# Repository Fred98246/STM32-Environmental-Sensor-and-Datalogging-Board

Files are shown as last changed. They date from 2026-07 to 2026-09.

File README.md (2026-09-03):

# Custom STM32 Environmental Sensor & Datalogging Board

## Project Overview
This repository contains the complete design files and source code for a custom, battery-powered STM32 microcontroller board designed for environmental monitoring and data logging. Measuring at a compact 40 x 58 mm, the board features integrated temperature, humidity, and ambient light sensors, alongside an SD card slot for local data storage. It includes a complete Li-Ion power management system with USB-C charging, load sharing, and battery protection. 

The user interface is driven by a rotary encoder and an external SPI display, making it suitable for standalone automated environments like humidity control or ambient monitoring.

## Repository Structure
*   **Hardware:** Contains the complete KiCad E.D.A. project files, including the schematic and the 4-layer PCB layout.
*   **Manufacturing:** Includes the generated Gerber files, Drill files, and sheets with the Bill of Materials (BOM) required for PCB fabrication and assembly.
*   **Firmware:** Contains the `STM32CubeMX` (`.ioc`) configuration file for peripheral initialization and the C/C++ code with the needed drivers.
*   **docs**: Contains component datasheets and a detailed Bill of Materials (BOM) spreadsheet

## Hardware Implementation Details

### Core Processing
*   **Microcontroller:** The board is powered by the STM32F103C8T6 ARM Cortex-M3 MCU.
*   **Clocking:** A 16MHz crystal oscillator (LFXTAL085871) is implemented to provide the precise clocking required for stable USB communication. 
*   **Debugging/Programming:** Connector for SWD programming, via ST-Link V2.

### Power Management
The power architecture is designed for safe, continuous operation whether plugged in or running on battery:
*   **Battery Charging:** Handled by the MCP73831/2 IC, drawing 5V from the USB-C port to charge a connected Li-Ion cell.
*   **Battery Protection:** An AP9101C IC, paired with dual ZXMN3B14F N-Channel MOSFETs, protects the battery from overcharge, overdischarge, and overcurrent scenarios.
*   **Load Sharing:** An AO3401A P-Channel MOSFET and an SS14 Schottky diode create a seamless load-sharing circuit. This ensures the system runs directly off USB power when plugged in, allowing the battery to charge optimally without system load interference.
*   **Regulation:** An AP2112K-3.3TRG1 LDO provides a stable 3.3V supply for the MCU and logic.

### Sensors & Interfaces
*   **Environmental Sensing:** Utilizes the SHT3x-DIS for high-precision temperature and humidity tracking via I2C.
*   **Light Sensing:** Incorporates the OPT3001DNPRQ1 ambient light sensor, also operating on the I2C bus.
*   **Storage:** A Molex 47219-2001 MicroSD card receptacle is routed via high-speed SPI for data logging in txt file.
*   **Connectivity:** USB-C port configured for USB 2.0 data and power. D3V3XA4B10LP TVS diode arrays are placed on both the USB data lines and the SD card lines to protect against electrostatic discharge (ESD).
*   USB-CDC Virtual COM Port Interface: Integrated full-speed USB communication between the STM32 and host PC, enabling real-time serial telemetry and diagnostic logging for hardware bring-up and physical fault isolation.
*   **User Input:** Hardware debounced rotary encoder footprint with integrated push-button functionality.

## Design Challenges & Signal Integrity
Designing this board within a 40x58mm footprint required careful attention to PCB stackup and signal routing:

*   **Component Footprints & Tolerances:** Extensive review of manufacturer datasheets was required to ensure precise footprint creation and component placement within the restricted 40x58mm board area.
*   **4-Layer Stackup:** To accommodate the component density and maintain strict signal integrity, a 4-layer PCB was utilized (Top Signal, Ground Plane, Power Plane, Bottom Signal). This continuous internal ground plane is critical for providing short return paths for high-frequency signals and minimizing electromagnetic interference (EMI). 
*   **USB Differential Routing:** The USB D+ and D- lines require 90-ohm differential impedance matching. The 4-layer stackup allowed for calculating precise trace widths and spacing over the internal ground plane to hit this impedance target, ensuring reliable USB enumeration and data transfer.
*   **MicroSD SPI Speeds:** Because SD card SPI operates at moderate speeds, it does not require strict impedance matching or length tuning. The 4-layer stackup provided the flexibility to route these signals easily through vias while maintaining a solid ground reference to minimize general EMI.
*   **Mixed-Signal Placement:** Analog sensor lines (I2C for SHT3x and OPT3001) are physically separated from high-speed digital traces (USB, SPI, and the 16MHz crystal) to prevent digital switching noise from coupling into the sensitive environmental readings.
*   **Firmware Architecture:** The C/C++ codebase leverages STM32 HAL libraries, structured with modular driver functions and a streamlined main loop to ensure non-blocking sensor reads and efficient peripheral management.

## Operational Flow & User Interface: 
The firmware is structured around an event-driven state machine that handles user interaction, data logging, and strict power efficiency:

*   **Startup & Menu Navigation:** The system is awakened by a physical press of the rotary encoder. The TFT display initializes and presents an interactive menu where the user can select to view Temperature, Humidity, or Ambient Light.
*   **Active Monitoring:** Upon selection, the screen continuously updates with real-time readings from the designated I2C sensor.
*   **Concurrent Datalogging & Telemetry:** While the system is awake, it automatically mounts the FATFS file system and appends the sensor readings to a `.txt` file on the MicroSD card at strict 10-second intervals. Simultaneously, this data is continuously broadcast over the USB-CDC COM port to a connected PC for live monitoring.
*   **Low-Power Sleep Mode:** To conserve battery, if the system detects no rotary encoder rotation or button clicks for 2 minutes, it automatically gracefully closes the SD card file, powers down the display, and puts the STM32 into a low-power `STOP` state. A subsequent button press triggers an EXTI hardware interrupt, waking the system back to full operation instantly.

## 🚀 Future Scope: Closed-Loop Automation
While currently operating as a standalone datalogger, this board was engineered to serve as the precision sensor node for future automated control systems. By linking the onboard environmental telemetry to external physical actuators (such as fans, humidifiers, or motorized blinds), the hardware will transition into a dynamic closed-loop control environment. 

The high-resolution empirical data currently gathered via the SD card and USB interface provides the foundation for mathematical system identification. This allows the physical environment's behavior to be accurately modeled in software like MATLAB, enabling the future calculation of transfer functions and the implementation of tuned PID or automated sequential control logic directly onto the STM32.

*   **Schematic**:




* **PCB**:



* **3D View**:



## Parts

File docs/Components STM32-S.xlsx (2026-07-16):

Component name | Part number | Data sheet | Price (Mouser) | Quantity
STM 32 Microconroler | STM32F103C8T6 | https://www.st.com/resource/en/datasheet/stm32f103c8.pdf | 6.05 € | 1
LDO Power 3.3V | AP2112K-3.3TRG1 | https://www.diodes.com//assets/Datasheets/AP2112.pdf | 0.22 € | 1
Li-Ion Battery Charger | MCP73831/2 | https://www.mouser.es/datasheet/3/282/1/MCP73831_Family_Data_Sheet_DS20001984H.pdf | 0.68 € | 1
Battery Protection | AP9101C | https://4donline.ihs.com/images/VipMasterIC/IC/DIOD/DIOD-S-A0007229744/DIOD-S-A0007229744-1.pdf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 | 0.25 € | 1
N-Channel Mosfets | ZXMN3B14F | https://www.mouser.es/datasheet/3/175/1/ZXMN3B14F.pdf | 1.11 € | 2
Temp/Humidity Sensor | SHT3x-DIS | https://www.mouser.es/datasheet/3/1278/1/080A7561932A882253F24EE2F1BFBB37F2FE6DCAD49B4883533175650C45BFA9.pdf | 2.13 € | 1
Light sensor | OPT3001DNPRQ1 | https://www.ti.com/lit/ds/symlink/opt3001-q1.pdf?ts=1783836413148 | 1.38 € | 1
P-Channel MOSFET | AO3401A | https://www.aosmd.com/sites/default/files/res/datasheets/AO3401A.pdf | 0.72 € | 1
Schottky diode | SS14 | https://www.vishay.com/docs/88746/ss12.pdf | 0.31 € | 1
TVS DIODE ARRAY for USB | D3V3XA4B10LP | https://www.diodes.com/assets/Datasheets/D3V3XA4B10LP.pdf | 0.36 € | 2
MicroSD Card | 47219-2001 | https://www.molex.com/en-us/products/part-detail-pdf/472192001?display=pdf | 1.41 € | 1
Cristal 16MHz | LFXTAL085871 | https://www.mouser.es/datasheet/3/1460/1/LFXTAL085871.pdf | 0.50 € | 1
Rotary Encoder | EC12 | https://es.aliexpress.com/item/1005005196870256.html?scm_id=1007.40050.354490.0&scm-url=1007.40050.354490.0 | €1.41 | 1
Manufacturing JLCPCB |  | https://cart.jlcpcb.com/quote?spm=jlcpcb.Public.2006 | €6.09 | 1
 |  | Total | 24.09

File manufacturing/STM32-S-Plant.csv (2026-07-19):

Reference | Qty | Value | DNP | Exclude from BOM | Exclude from Board | Footprint | Datasheet
C1,C2 | 2 | 1u |  |  |  | Capacitor_SMD:C_0402_1005Metric | ~
C3,C4 | 2 | 4.7u |  |  |  | Capacitor_SMD:C_0805_2012Metric | ~
C5,C7,C8,C9,C11,C12,C16,C17,C18,C24 | 10 | 100n |  |  |  | Capacitor_SMD:C_0402_1005Metric | ~
C6,C10,C15 | 3 | 10u |  |  |  | Capacitor_SMD:C_0805_2012Metric | ~
C19,C20,C21 | 3 | 10n |  |  |  | Capacitor_SMD:C_0402_1005Metric | ~
C22,C23 | 2 | 10p |  |  |  | Capacitor_SMD:C_0402_1005Metric | ~
D1,D6 | 2 | D3V3XA4B10LP-7 |  |  |  | SamacSys_Parts:D3V3XA4B10LP7 | https://www.diodes.com/assets/Datasheets/D3V3XA4B10LP.pdf
D4 | 1 | Charging LED |  |  |  | Capacitor_SMD:C_0603_1608Metric | ~
D5 | 1 | SS14 |  |  |  | SamacSys_Parts:DIOM5026X230N | https://datasheet.lcsc.com/szlcsc/1911061831_SLKORMICRO-Elec-SS14_C444721.pdf
IC1 | 1 | AP2112K-3.3TRG1 |  |  |  | SamacSys_Parts:SOT95P270X145-5N | https://www.diodes.com//assets/Datasheets/AP2112.pdf
IC2 | 1 | AP9101CAK-AKTRG1 |  |  |  | SamacSys_Parts:SOT95P270X145-5N | https://www.diodes.com/assets/Datasheets/AP9101C.pdf
IC4 | 1 | MCP73831-2ATI_OT |  |  |  | SamacSys_Parts:SOT95P270X145-5N | http://ww1.microchip.com/downloads/en/DeviceDoc/20001984g.pdf
IC6 | 1 | OPT3001DNPRQ1 |  |  |  | SamacSys_Parts:SON65P200X200X65-7N-D | http://www.ti.com/lit/gpn/OPT3001-Q1
IC7 | 1 | SHT3X-DIS |  |  |  | SamacSys_Parts:SON50P250X250X100-9N-D
IC8 | 1 | STM32F103C8T6 |  |  |  | SamacSys_Parts:QFP50P900X900X160-48N | https://www.st.com/resource/en/datasheet/stm32f103c8.pdf
J1 | 1 | Battery Connector |  |  |  | Connector_PinHeader_2.54mm:PinHeader_1x02_P2.54mm_Vertical | ~
J2 | 1 | USB_C_Receptacle_USB2.0_16P |  |  |  | Connector_USB:USB_C_Receptacle_GCT_USB4105-xx-A_16P_TopMnt_Horizontal | https://www.usb.org/sites/default/files/documents/usb_type-c.zip
J3 | 1 | DISPLAY |  |  |  | Connector_PinHeader_2.54mm:PinHeader_1x08_P2.54mm_Vertical | ~
J4 | 1 | 47219-2001 |  |  |  | SamacSys_Parts:472192001 | http://www.molex.com/molex/products/datasheet.jsp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
J5 | 1 | DEBUG CONNECTOR ST-LINK |  |  |  | Connector_PinHeader_2.54mm:PinHeader_1x07_P2.54mm_Vertical | ~
Q1 | 1 | AO3401A |  |  |  | SamacSys_Parts:SOT95P280X125-3N | http://www.aosmd.com/pdfs/datasheet/AO3401A.pdf
Q2,Q3 | 2 | ZXMN3B14FTA |  |  |  | SamacSys_Parts:ZXMN3B14FTA | https://www.diodes.com/assets/Datasheets/ZXMN3B14F.pdf
R1,R9,R19,R20,R21,R22 | 6 | 10K |  |  |  | Resistor_SMD:R_0603_1608Metric | ~
R2 | 1 | 470 |  |  |  | Resistor_SMD:R_0603_1608Metric | ~
R3 | 1 | 2K |  |  |  | Resistor_SMD:R_0603_1608Metric | ~
R4 | 1 | 330 |  |  |  | Resistor_SMD:R_0603_1608Metric | ~
R5 | 1 | 2.7K |  |  |  | Resistor_SMD:R_0603_1608Metric | ~
R6 | 1 | 100K |  |  |  | Resistor_SMD:R_0603_1608Metric | ~
R7,R8 | 2 | 5.1K |  |  |  | Resistor_SMD:R_0603_1608Metric | ~
R10,R16,R17,R18 | 4 | 10k |  |  |  | Resistor_SMD:R_0603_1608Metric | ~
SW1 | 1 | RotaryEncoder_Switch |  |  |  | Rotary_Encoder:RotaryEncoder_Alps_EC11E-Switch_Vertical_H20mm_MountingHoles | ~
Y2 | 1 | LFXTAL085871 |  |  |  | SamacSys_Parts:LFXTAL085871 | https://www.mouser.de/datasheet/3/1460/1/LFXTAL085871.pdf

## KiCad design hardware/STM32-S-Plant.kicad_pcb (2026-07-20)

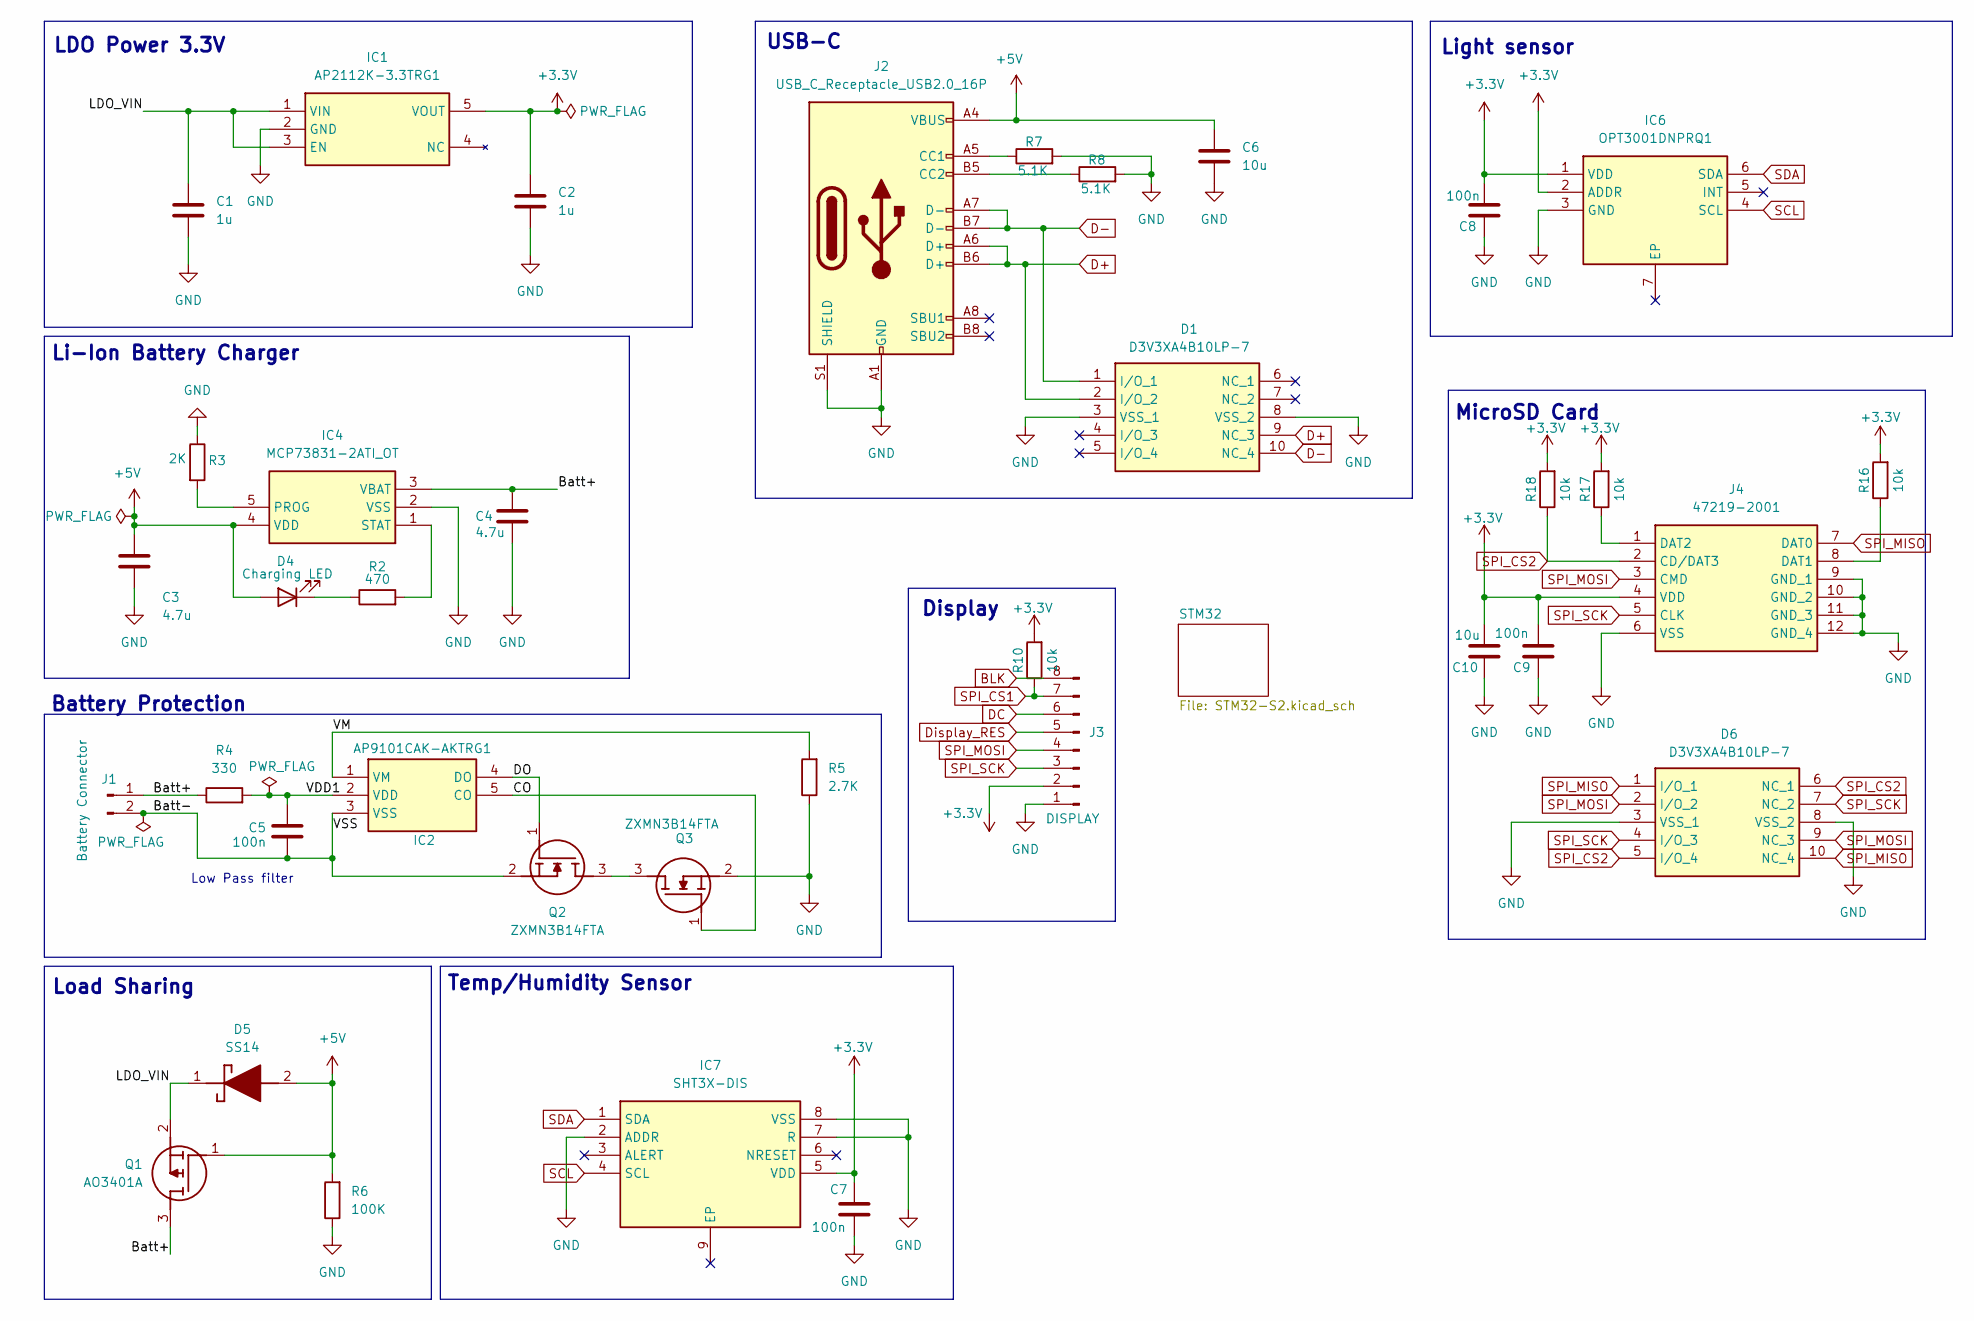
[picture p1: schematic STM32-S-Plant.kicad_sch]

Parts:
C1, C2: 1u; C_0402_1005Metric
C3, C4: 4.7u; C_0805_2012Metric
C5, C7, C8, C9: 100n; C_0402_1005Metric
C6, C10: 10u; C_0805_2012Metric
D1, D6: D3V3XA4B10LP-7; D3V3XA4B10LP7; Manufacturer_Part_Number D3V3XA4B10LP-7; Mouser Part Number 621-D3V3XA4B10LP-7
D4: Charging LED; C_0603_1608Metric
D5: SS14; DIOM5026X230N; Manufacturer_Part_Number SS14
IC1: AP2112K-3.3TRG1; SOT95P270X145-5N; Manufacturer_Part_Number AP2112K-3.3TRG1; Mouser Part Number 621-AP2112K-3.3TRG1
IC2: AP9101CAK-AKTRG1; SOT95P270X145-5N; Manufacturer_Part_Number AP9101CAK-AKTRG1; Mouser Part Number 621-AP9101CAK-AKTRG1
IC4: MCP73831-2ATI_OT; SOT95P270X145-5N; Manufacturer_Part_Number MCP73831-2ATI/OT
IC6: OPT3001DNPRQ1; SON65P200X200X65-7N-D; Manufacturer_Part_Number OPT3001DNPRQ1; Mouser Part Number 595-OPT3001DNPRQ1
IC7: SHT3X-DIS; SON50P250X250X100-9N-D; Manufacturer_Part_Number SHT3X-DIS
J1: Battery Connector; PinHeader_1x02_P2.54mm_Vertical
J2: USB_C_Receptacle_USB2.0_16P; USB_C_Receptacle_GCT_USB4105-xx-A_16P_TopMnt_Horizontal
J3: DISPLAY; PinHeader_1x08_P2.54mm_Vertical
J4: 47219-2001; 472192001; Manufacturer_Part_Number 47219-2001; Mouser Part Number 538-47219-2001
Q1: AO3401A; SOT95P280X125-3N; Manufacturer_Part_Number AO3401A
Q2, Q3: ZXMN3B14FTA; Manufacturer_Part_Number ZXMN3B14FTA; Mouser Part Number 522-ZXMN3B14FTA
R2: 470; R_0603_1608Metric
R3: 2K; R_0603_1608Metric
R4: 330; R_0603_1608Metric
R5: 2.7K; R_0603_1608Metric
R6: 100K; R_0603_1608Metric
R7, R8: 5.1K; R_0603_1608Metric
R10, R16, R17, R18: 10k; R_0603_1608Metric

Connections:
+3.3V: C2.1, C7.1, C8.2, C9.2, C10.2, IC1.5 (VOUT), IC6.1 (VDD), IC6.2 (ADDR), IC7.5 (VDD), J3.2, J4.4 (VDD), R10.2, R16.2, R17.2, R18.2; also elsewhere on the board
+5V: C3.1, C6.1, D4.2 (A), D5.2 (A), IC4.4 (VDD), J2.A4 (VBUS), J2.A9 (VBUS), J2.B4 (VBUS), J2.B9 (VBUS), Q1.1 (G), R6.2
/Batt+: C4.1, IC4.3 (VBAT), J1.1, Q1.3 (D), R4.1
/Batt-: C5.2, IC2.3 (VSS), J1.2, Q2.2 (S)
/CO: IC2.5 (CO), Q3.1 (G)
/DO: IC2.4 (DO), Q2.1 (G)
/LDO_VIN: C1.1, D5.1 (K), IC1.1 (VIN), IC1.3 (EN), Q1.2 (S)
/VDD1: C5.1, IC2.2 (VDD), R4.2
/VM: IC2.1 (VM), R5.2
BLK: J3.8; also elsewhere on the board
D+: D1.2 (I/O_2), D1.9 (NC_3), J2.A6 (D+), J2.B6 (D+); also elsewhere on the board
D-: D1.1 (I/O_1), D1.10 (NC_4), J2.A7 (D-), J2.B7 (D-); also elsewhere on the board
DC: J3.6; also elsewhere on the board
Display_RES: J3.5; also elsewhere on the board
GND: C1.2, C2.2, C3.2, C4.2, C6.2, C7.2, C8.1, C9.1, C10.1, D1.3 (VSS_1), D1.8 (VSS_2), D6.3 (VSS_1), D6.8 (VSS_2), IC1.2 (GND), IC4.2 (VSS), IC6.3 (GND), IC7.2 (ADDR), IC7.7 (R), IC7.8 (VSS), J2.A1 (GND), J2.A12 (GND), J2.B1 (GND), J2.B12 (GND), J2.S1 (SHIELD), J3.1, J4.6 (VSS), J4.9 (GND_1), J4.10 (GND_2), J4.11 (GND_3), J4.12 (GND_4), Q3.2 (S), R3.1, R5.1, R6.1, R7.2, R8.2; also elsewhere on the board
unnamed: D4.1 (K), R2.1
unnamed: IC4.5 (PROG), R3.2
unnamed: IC4.1 (STAT), R2.2
unnamed: J2.A5 (CC1), R7.1
unnamed: J2.B5 (CC2), R8.1
unnamed: J4.8 (DAT1), R16.1
unnamed: J4.1 (DAT2), R17.1
unnamed: Q2.3 (D), Q3.3 (D)
SCL: IC6.4 (SCL), IC7.4 (SCL); also elsewhere on the board
SDA: IC6.6 (SDA), IC7.1 (SDA); also elsewhere on the board
SPI_CS1: J3.7, R10.1; also elsewhere on the board
SPI_CS2: D6.5 (I/O_4), D6.6 (NC_1), J4.2 (CD/DAT3), R18.1; also elsewhere on the board
SPI_MISO: D6.1 (I/O_1), D6.10 (NC_4), J4.7 (DAT0); also elsewhere on the board
SPI_MOSI: D6.2 (I/O_2), D6.9 (NC_3), J3.4, J4.3 (CMD); also elsewhere on the board
SPI_SCK: D6.4 (I/O_3), D6.7 (NC_2), J3.3, J4.5 (CLK); also elsewhere on the board

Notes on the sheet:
Light sensor
Display
USB-C
Low Pass filter
Load Sharing
MicroSD Card
Battery Protection
LDO Power 3.3V
Li-Ion Battery Charger
Temp/Humidity Sensor

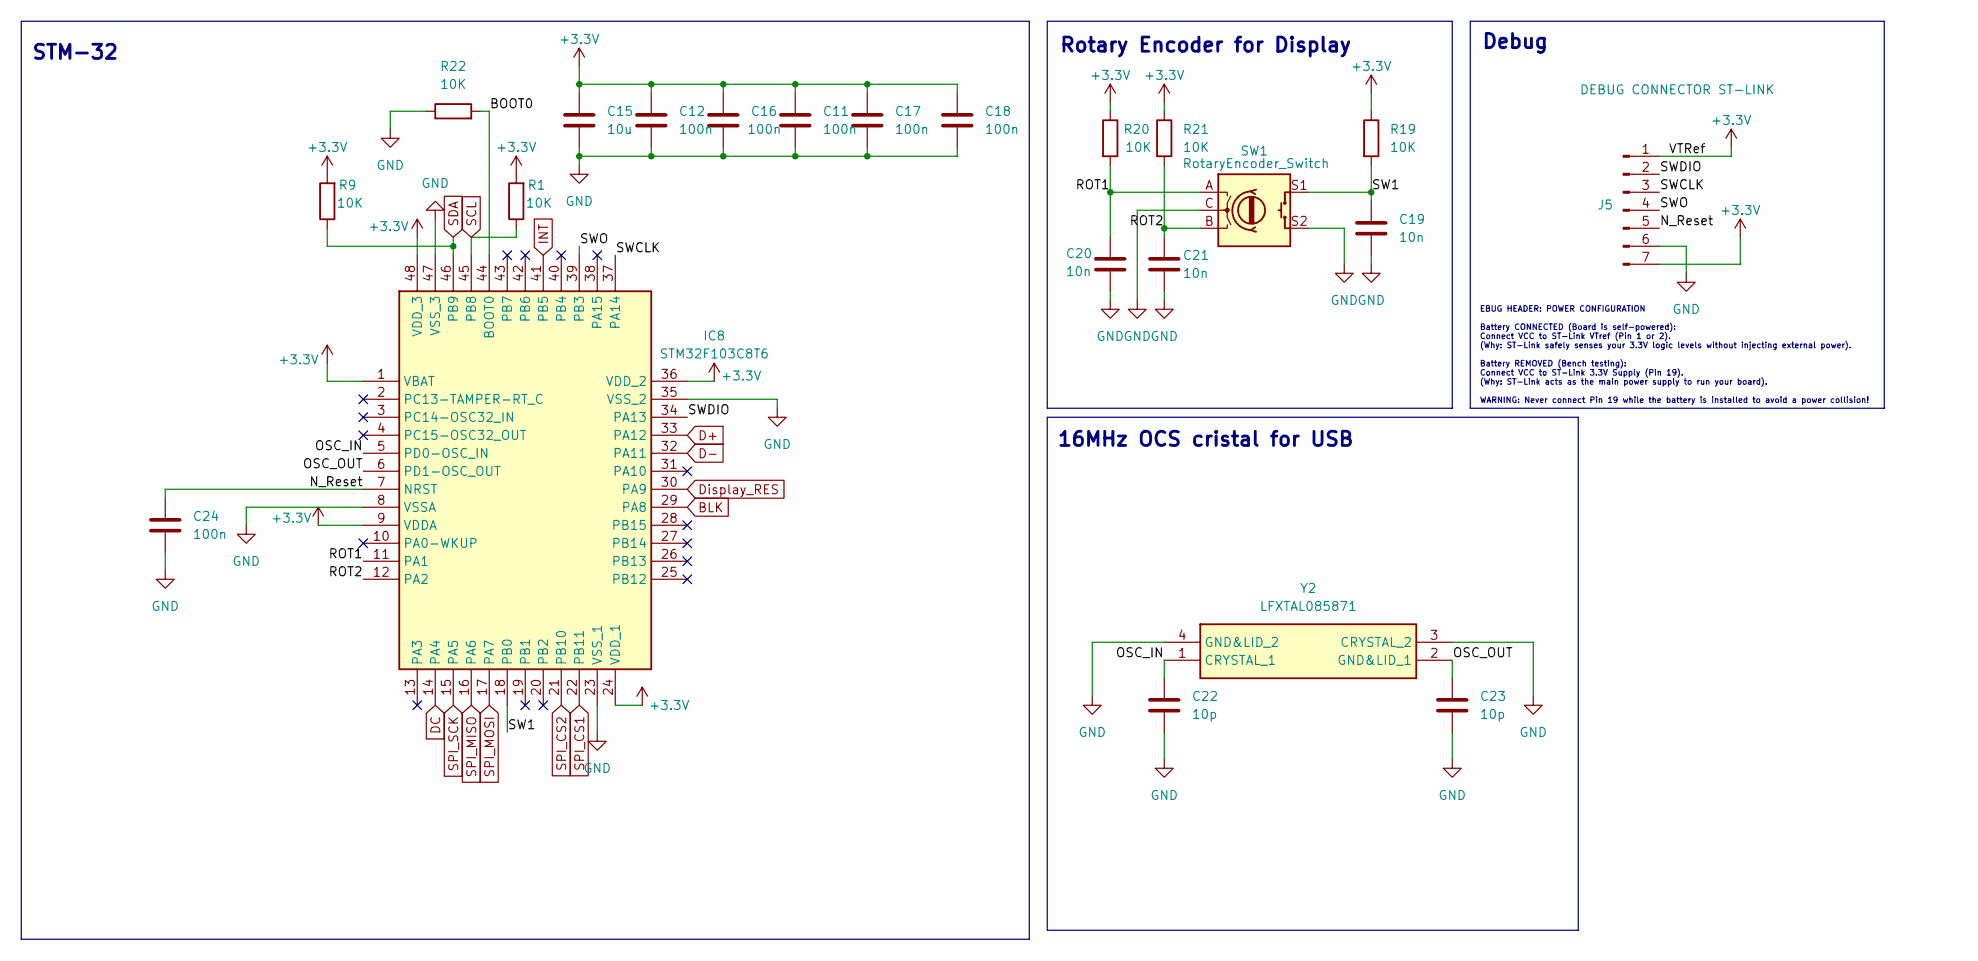
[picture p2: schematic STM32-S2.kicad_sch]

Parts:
C11, C12, C16, C17, C18, C24: 100n; C_0402_1005Metric
C15: 10u; C_0805_2012Metric
C19, C20, C21: 10n; C_0402_1005Metric
C22, C23: 10p; C_0402_1005Metric
IC8: STM32F103C8T6; QFP50P900X900X160-48N; Manufacturer_Part_Number STM32F103C8T6; Mouser Part Number 511-STM32F103C8T6
J5: DEBUG CONNECTOR ST-LINK; PinHeader_1x07_P2.54mm_Vertical
R1, R9, R19, R20, R21, R22: 10K; R_0603_1608Metric
SW1: RotaryEncoder_Switch; RotaryEncoder_Alps_EC11E-Switch_Vertical_H20mm_MountingHoles
Y2: LFXTAL085871; Manufacturer_Part_Number LFXTAL085871

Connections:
+3.3V: C11.1, C12.1, C15.1, C16.1, C17.1, C18.1, IC8.1 (VBAT), IC8.9 (VDDA), IC8.24 (VDD_1), IC8.36 (VDD_2), IC8.48 (VDD_3), J5.1, J5.7, R1.2, R9.2, R19.1, R20.1, R21.1; also elsewhere on the board
/STM32/BOOT0: IC8.44 (BOOT0), R22.2
/STM32/N_Reset: C24.1, IC8.7 (NRST), J5.5
/STM32/OSC_IN: C22.1, IC8.5 (PD0-OSC_IN), Y2.1 (CRYSTAL_1)
/STM32/OSC_OUT: C23.1, IC8.6 (PD1-OSC_OUT), Y2.2 (GND&LID_1)
/STM32/ROT1: C20.1, IC8.11 (PA1), R20.2, SW1.A
/STM32/ROT2: C21.1, IC8.12 (PA2), R21.2, SW1.B
/STM32/SW1: C19.1, IC8.18 (PB0), R19.2, SW1.S1
/STM32/SWCLK: IC8.37 (PA14), J5.3
/STM32/SWDIO: IC8.34 (PA13), J5.2
/STM32/SWO: IC8.39 (PB3), J5.4
BLK: IC8.29 (PA8); also elsewhere on the board
D+: IC8.33 (PA12); also elsewhere on the board
D-: IC8.32 (PA11); also elsewhere on the board
DC: IC8.14 (PA4); also elsewhere on the board
Display_RES: IC8.30 (PA9); also elsewhere on the board
GND: C11.2, C12.2, C15.2, C16.2, C17.2, C18.2, C19.2, C20.2, C21.2, C22.2, C23.2, C24.2, IC8.8 (VSSA), IC8.23 (VSS_1), IC8.35 (VSS_2), IC8.47 (VSS_3), J5.6, R22.1, SW1.C, SW1.S2, Y2.3 (CRYSTAL_2), Y2.4 (GND&LID_2); also elsewhere on the board
INT: IC8.41 (PB5)
SCL: IC8.45 (PB8), R1.1; also elsewhere on the board
SDA: IC8.46 (PB9), R9.1; also elsewhere on the board
SPI_CS1: IC8.22 (PB11); also elsewhere on the board
SPI_CS2: IC8.21 (PB10); also elsewhere on the board
SPI_MISO: IC8.16 (PA6); also elsewhere on the board
SPI_MOSI: IC8.17 (PA7); also elsewhere on the board
SPI_SCK: IC8.15 (PA5); also elsewhere on the board

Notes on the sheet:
Debug
STM-32
Rotary Encoder for Display
16MHz OCS cristal for USB
EBUG HEADER: POWER CONFIGURATION Battery CONNECTED (Board is self-powered): Connect VCC to ST-Link VTref (Pin 1 or 2). (Why: ST-Link safely senses your 3.3V logic levels without injecting external power). Battery REMOVED (Bench testing): Connect VCC to ST-Link 3.3V Supply (Pin 19). (Why: ST-Link ac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

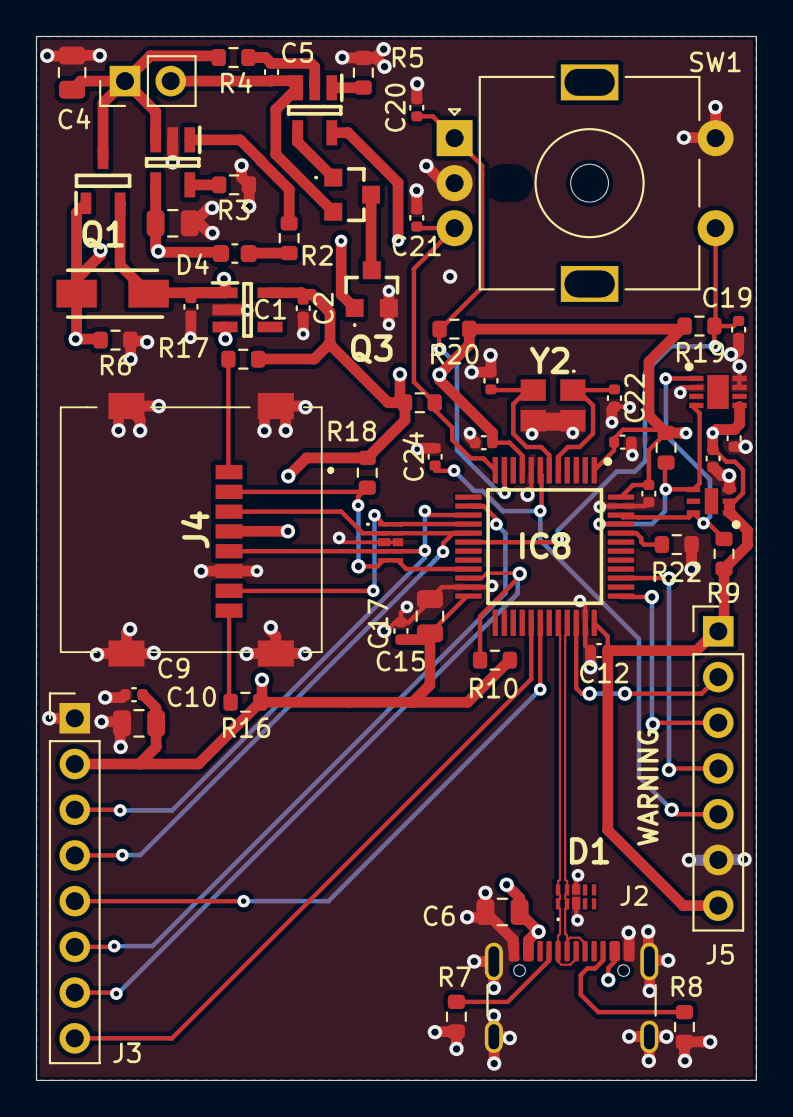
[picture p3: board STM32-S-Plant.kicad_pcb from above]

Board: 4 copper layers, 40.0 x 58.0 mm, 59 parts (0 on the bottom side), 40 nets.

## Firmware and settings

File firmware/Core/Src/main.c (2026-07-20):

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
/* Includes ------------------------------------------------------------------*/
#include "main.h"
#include "fatfs.h"
#include "usb_device.h"

/* USER CODE BEGIN Includes */
#include "st7735.h"
#include <stdio.h>
#include <string.h>
#include <stdarg.h>
#include "usbd_cdc_if.h"
/* USER CODE END Includes */

I2C_HandleTypeDef hi2c1;

SPI_HandleTypeDef hspi1;

/* USER CODE BEGIN PV */
void myprintf(const char *fmt, ...);

/* USER CODE END PV */

void SystemClock_Config(void);
static void MX_GPIO_Init(void);
static void MX_I2C1_Init(void);
static void MX_SPI1_Init(void);
/* USER CODE BEGIN PFP */
void startup(void);
void read_sensor(void);
void sleep(void);
void update_display(void);
void sdcard_write(void);

/* USER CODE END PFP */

/* USER CODE BEGIN 0 */
uint32_t last_activity_time = 0;
uint8_t current_state = 0; // 0: Menu, 1: Temp, 2: Hum, 3: Light
uint8_t menu_selection = 0;
uint32_t last_interrupt_time = 0;

float current_temp = 0.0f;
float current_hum = 0.0f;
float current_light = 0.0f;

void myprintf(const char *fmt, ...) {
  static char buffer[256];
  va_list args;
  va_start(args, fmt);
  vsnprintf(buffer, sizeof(buffer), fmt, args);
  va_end(args);

  int len = strlen(buffer);
  CDC_Transmit_FS((uint8_t*)buffer, len);

}
/* USER CODE END 0 */

/**
  * @brief  The application entry point.
  * @retval int
  */
int main(void)
{

  /* MCU Configuration--------------------------------------------------------*/

  /* Reset of all peripherals, Initializes the Flash interface and the Systick. */
  HAL_Init();

  /* Configure the system clock */
  SystemClock_Config();

  /* Initialize all configured peripherals */
  MX_GPIO_Init();
  MX_I2C1_Init();
  MX_SPI1_Init();
  MX_FATFS_Init();
  MX_USB_DEVICE_Init();
  /* USER CODE BEGIN 2 */
  startup();
  last_activity_time = HAL_GetTick();
  uint32_t last_log_time = HAL_GetTick(); // Timer to track SD card writes

  /* USER CODE END 2 */

  /* Infinite loop */
  /* USER CODE BEGIN WHILE */
  while (1)
  {
	  // 1. Check for 2-minute inactivity timeout (120,000 ms)
	        if ((HAL_GetTick() - last_activity_time) > 120000) {
	            sleep();

	            // --- MCU wakes up and resumes execution here ---
	            // Reset the timer so it doesn't immediately go back to sleep
	            last_activity_time = HAL_GetTick();
	        }

	        // 2. Poll the I2C sensors for data on demand
	        read_sensor();

	        // 3. Update the ST7735 screen based on the current state machine
	        update_display();

	        // 4. Log to SD card every 10 seconds (10,000 ms)
	        if ((HAL_GetTick() - last_log_time) > 10000) {
	                    sdcard_write();
	                    last_log_time = HAL_GetTick(); // Reset the timer
	                }
	        // 4. Small delay to prevent screen flickering and bus overload
	        HAL_Delay(100);
    /* USER CODE END WHILE */

    /* USER CODE BEGIN 3 */
  }
  /* USER CODE END 3 */
}

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
/* USER CODE BEGIN 4 */

void HAL_GPIO_EXTI_Callback(uint16_t GPIO_Pin)
{
	uint32_t current_time = HAL_GetTick();

	    // Ignore bounces faster than 50ms
	    if ((current_time - last_interrupt_time) > 50) {
	        last_activity_time = current_time;
	        last_interrupt_time = current_time;

	        if (GPIO_Pin == SW1_Pin) {
	            if (current_state == 0) current_state = 1;
	            else current_state = 0;
	            myprintf("Button Clicked! New State: %d\r\n", current_state);
	        }
	        else if (GPIO_Pin == ROT1_Pin) {
	            if (current_state == 0) {
	                if (HAL_GPIO_ReadPin(GPIOA, ROT2_Pin) == GPIO_PIN_SET) {
	                    if (menu_selection < 2) menu_selection++;
	                } else {
	                    if (menu_selection > 0) menu_selection--;
	                }
	                myprintf("Encoder Turned! Selection: %d\r\n", menu_selection);
	            }
	        }
	    }
}

void startup(void){

		// 1. Turn on the display backlight
	    HAL_GPIO_WritePin(BLK_GPIO_Port, BLK_Pin, GPIO_PIN_SET);

	    // 2. HARDWARE RESET: Pull low for 50ms, then pull high for 50ms
	    HAL_GPIO_WritePin(Display_RES_GPIO_Port, ST7735_RES_Pin, GPIO_PIN_RESET);
	    HAL_Delay(50);
	    HAL_GPIO_WritePin(Display_RES_GPIO_Port, ST7735_RES_Pin, GPIO_PIN_SET);
	    HAL_Delay(50);

	    myprintf("\r\n--- SYSTEM BOOTING ---\r\n");
	    myprintf("Initializing TFT Display...\r\n");
	    // 3. Initialize the ST7735 Display
	    ST7735_Init();
	    ST7735_FillScreen(ST7735_BLACK);
	    // 4. Configure the OPT3001 Light Sensor
	    // It boots in shutdown mode. We write 0xC810 to the Configuration Register (0x01)
	    // to set it to Continuous Conversion mode with an 800ms integration time.
	    // Note: Assuming I2C address 0x88 (0x44 shifted left by 1).
	    myprintf("Configuring OPT3001 Light Sensor...\r\n");

	    uint8_t opt_config[3] = {0x01, 0xC8, 0x10};
	    HAL_I2C_Master_Transmit(&hi2c1, 0x8A, opt_config, 3, HAL_MAX_DELAY);
	    myprintf("Light sensor configured successfully!\r\n");
	    // 5. Mount the MicroSD Card
	    // The '1' at the end forces FatFs to mount immediately so we can catch errors early.
	    // (You will uncomment this once FatFs is fully enabled in CubeMX)
	    // if (f_mount(&SDFatFs, "", 1) != FR_OK) {
	    //     // Optional: Draw an "SD Error" message on the screen if it fails
}

void read_sensor(void){
		uint8_t sht_data[6];
	    uint8_t opt_data[2];

	    // Command 0x2400: High repeatability measurement, clock stretching disabled
	    uint8_t sht_cmd[2] = {0x24, 0x00};

	    // =========================================================================
	    // 1. SHT3x-DIS (Temperature & Humidity)
	    // Hardware: ADDR to GND -> 0x44 -> Shifted for HAL: 0x88
	    // =========================================================================

	    // Send the measurement command
	    HAL_I2C_Master_Transmit(&hi2c1, 0x88, sht_cmd, 2, HAL_MAX_DELAY);

	    // Wait for the measurement to complete (High repeatability takes max 15ms)
	    HAL_Delay(15);

	    // Read the 6 bytes: Temp MSB, Temp LSB, Temp CRC, Hum MSB, Hum LSB, Hum CRC
	    if (HAL_I2C_Master_Receive(&hi2c1, 0x88, sht_data, 6, HAL_MAX_DELAY) == HAL_OK) {

	        // Combine MSB and LSB into 16-bit raw integers
	        uint16_t raw_temp = (sht_data[0] << 8) | sht_data[1];
	        uint16_t raw_hum = (sht_data[3] << 8) | sht_data[4];

	        // Apply mathematical conversion formulas
	        current_temp = -45.0f + 175.0f * ((float)raw_temp / 65535.0f);
	        current_hum = 100.0f * ((float)raw_hum / 65535.0f);
	    }else {
	        myprintf("[ERROR] SHT3x Read Failed!\r\n");
	    }

	    // =========================================================================
	    // 2. OPT3001-Q1 (Ambient Light)
	    // Hardware: ADDR to 3.3V -> 0x45 -> Shifted for HAL: 0x8A
	    // =========================================================================

	    // Because we set continuous conversion in startup(), we simply read the Result Register (0x00)
	    if (HAL_I2C_Mem_Read(&hi2c1, 0x8A, 0x00, I2C_MEMADD_SIZE_8BIT, opt_data, 2, HAL_MAX_DELAY) == HAL_OK) {

	        // Combine MSB and LSB into a 16-bit raw integer
	        uint16_t raw_light = (opt_data[0] << 8) | opt_data[1];

	        // Extract the 4-bit Exponent and 12-bit Fractional result using bitwise masking
	        uint16_t exponent = (raw_light & 0xF000) >> 12;
	        uint16_t fractional = raw_light & 0x0FFF;

	        // Calculate final Lux value using bitwise shifting for the 2^E exponent math
	        current_light = 0.01f * (1 << exponent) * fractional;
	    }else {
	        myprintf("[ERROR] OPT3001 Read Failed!\r\n");
	    }
}

void sleep(void){
	// Let us know over USB that it's going to sleep
	    myprintf("\r\nEntering STOP mode.\r\n");
	    HAL_Delay(10); // Crucial: Give the USB buffer a split second to flush out the text before halting clocks!

		// --- 1. PREPARE FOR SLEEP ---
		    // Turn off the display backlight to save battery
		    HAL_GPIO_WritePin(BLK_GPIO_Port, BLK_Pin, GPIO_PIN_RESET);

		    // Suspend the 1ms system timer.
		    // If we don't do this, the SysTick interrupt will wake the MCU up every 1 millisecond!
		    HAL_SuspendTick();

		    // --- 2. ENTER STOP MODE ---
		    // The processor stops executing code exactly at this line.
		    // It will remain asleep here until a hardware interrupt (EXTI) occurs.
		    // Because you configured SW1_Pin and ROT1_Pin as EXTI in CubeMX,
		    // pressing or turning the encoder will automatically wake it up.
		    HAL_PWR_EnterSTOPMode(PWR_LOWPOWERREGULATOR_ON, PWR_STOPENTRY_WFI);

		    // =========================================================
		    //               MCU IS ASLEEP HERE
		    // =========================================================

		    // --- 3. WAKE UP SEQUENCE ---
		    // Code execution resumes here immediately after the EXTI interrupt fires.

		    // STOP mode disables the main oscillator (HSE) and the PLL to save power.
		    // We must reconfigure the clocks before doing anything else, or the MCU will run very slowly.
		    SystemClock_Config();

		    // Resume the 1ms system timer so HAL_Delay() and HAL_GetTick() work again
		    HAL_ResumeTick();

		    // Turn the display backlight back on
		    HAL_GPIO_WritePin(BLK_GPIO_Port, BLK_Pin, GPIO_PIN_SET);

	    // Let us know over USB that it successfully woke up and restored its clocks
	    myprintf("\r\nWoke up! Clocks restored.\r\n");
}

void update_display(void){

	char buffer[32]; // Buffer to hold our formatted text strings

	    if (current_state == 0) {
	        // --- MAIN MENU ---
	        // Highlight the selected option by making it GREEN, others WHITE
	        uint16_t color0 = (menu_selection == 0) ? ST7735_GREEN : ST7735_WHITE;
	        uint16_t color1 = (menu_selection == 1) ? ST7735_GREEN : ST7735_WHITE;
	        uint16_t color2 = (menu_selection == 2) ? ST7735_GREEN : ST7735_WHITE;

	        // Draw the menu text (assuming Font_7x10 exists in your fonts.h)
	        ST7735_WriteString(10, 20, "1. Temperature", Font_7x10, color0, ST7735_BLACK);
	        ST7735_WriteString(10, 40, "2. Humidity   ", Font_7x10, color1, ST7735_BLACK);
	        ST7735_WriteString(10, 60, "3. Light      ", Font_7x10, color2, ST7735_BLACK);

	    } else if (current_state == 1) {
	        // --- DATA VIEW ---
	        // We add extra spaces at the end of the strings to overwrite any leftover pixels
	        // from previous longer numbers, acting as a quick way to clear the line.
	        if (menu_selection == 0) {
	        	int t_int = (int)current_temp;
	        	int t_dec = (int)(current_temp * 100) % 100;
	        	if(t_dec < 0) t_dec = -t_dec; // Handle negative temps
	        	sprintf(buffer, "Temp: %d.%02d C  ", t_int, t_dec);
	            ST7735_WriteString(10, 40, buffer, Font_7x10, ST7735_WHITE, ST7735_BLACK);
	        }
	        else if (menu_selection == 1) {
	        	int h_int = (int)current_hum;
	        	int h_dec = (int)(current_hum * 100) % 100;
	        	sprintf(buffer, "Hum: %d.%02d %%   ", h_int, h_dec);
	            ST7735_WriteString(10, 40, buffer, Font_7x10, ST7735_WHITE, ST7735_BLACK);
	        }
	        else if (menu_selection == 2) {
	        	sprintf(buffer, "Light: %d lx  ", (int)current_light);
	            ST7735_WriteString(10, 40, buffer, Font_7x10, ST7735_WHITE, ST7735_BLACK);
	        }
	    }
}


void sdcard_write(void){
    FATFS FatFs;
    FIL fil;
    FRESULT fres;
    char log_buffer[100]; // Buffer to hold our formatted string
    UINT bytesWrote;

    // 1. Mount the file system
    fres = f_mount(&FatFs, "", 1);
    if (fres != FR_OK) {
        myprintf("SD Mount error: %i\r\n", fres);
        return; // Stop here if mount fails
    }

    // 2. Open the file (FA_OPEN_ALWAYS creates it if it doesn't exist)
    fres = f_open(&fil, "data.txt", FA_WRITE | FA_OPEN_ALWAYS);

    if(fres == FR_OK) {
        // *** THE FIX: Move the "cursor" to the end of the file so we don't overwrite! ***
        f_lseek(&fil, f_size(&fil));

        // 3. Format the sensor data into a text string
        int t_int = (int)current_temp;
        int t_dec = (int)(current_temp * 100) % 100;
        if(t_dec < 0) t_dec = -t_dec;
        int h_int = (int)current_hum;
        int h_dec = (int)(current_hum * 100) % 100;

        sprintf(log_buffer, "Temp: %d.%02d C, Hum: %d.%02d %%, Light: %d lx\r\n", t_int, t_dec, h_int, h_dec, (int)current_light);

        // 4. Write the string to the SD card
        fres = f_write(&fil, log_buffer, strlen(log_buffer), &bytesWrote);

        if(fres == FR_OK) {
            myprintf("Logged to SD: %s", log_buffer); // Echo to USB for debugging
        } else {
            myprintf("SD Write error: %i\r\n", fres);
        }

        // 5. Close the file to finalize and save the data to the silicon
        f_close(&fil);
    } else {
        myprintf("SD Open error: %i\r\n", fres);
    }

    // 6. Unmount the drive (Important to prevent corruption if power is lost)
    f_mount(NULL, "", 0);
}


/* USER CODE END 4 */
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


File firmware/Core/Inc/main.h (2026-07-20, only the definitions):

#define ROT1_Pin GPIO_PIN_1
#define ROT1_GPIO_Port GPIOA
#define ROT2_Pin GPIO_PIN_2
#define ROT2_GPIO_Port GPIOA
#define DC_Pin GPIO_PIN_4
#define DC_GPIO_Port GPIOA
#define SW1_Pin GPIO_PIN_0
#define SW1_GPIO_Port GPIOB
#define SPI_CS2_Pin GPIO_PIN_10
#define SPI_CS2_GPIO_Port GPIOB
#define SPI_CS1_Pin GPIO_PIN_11
#define SPI_CS1_GPIO_Port GPIOB
#define BLK_Pin GPIO_PIN_8
#define BLK_GPIO_Port GPIOA
#define Display_RES_Pin GPIO_PIN_9
#define Display_RES_GPIO_Port GPIOA
#define SD_SPI_HANDLE hspi1

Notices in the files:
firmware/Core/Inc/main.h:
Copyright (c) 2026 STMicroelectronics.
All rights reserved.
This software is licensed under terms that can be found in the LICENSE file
